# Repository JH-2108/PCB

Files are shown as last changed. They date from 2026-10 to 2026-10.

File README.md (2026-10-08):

# Small devboard 

A custom RP2040-based development board designed from scratch in KiCAD as part of Hack Club Half Life. 

The DevBoard is a compact general-purpose development platform with native USB-C connectivity, external QSPI flash, 3.3V power regulation, GPIO breakout, onboard controls, and a status LED. The board is intended to be used for embedded programming, electronics experimentation, robotics, sensors, displays, and future hardware projects. 

# Features 
- Raspberry Pi RP2040 microcontroller
- Native USB-C connectivity
- External QSPI flash
- 12 MHz crystal oscillator
- 3.3V power regulation
- 2x20 GPIO breakout pins
- BOOTSEL and RESET buttons
- Onboard status LED
- SMD components
- Custom PCB designed in KiCAD

# Hardware 
The board is built around the RP2040 and follows the required circuity for its power, clock, USB, and external flash interfaces. 

# Main components
- RP2040 MCU
- W25Q128 QSPI flash
- 12 MHz crystal
- USB-C connector
- 3.3V LDO regulator
- Decoupling and filtering capacitors
- USB-C CC resistors
- GPIO headers
- RESET and BOOTSEL buttons
- Status LED

# Firmware
The devboard will be programmed using the Raspberry Pi Pico SDK and C/C++. 

The initial firmware will provide: 
- RP2040 boot and initialization
- USB connectivity
- GPIO testing
- Status LED control
- Board diagnostics
- USB serial communication

A diagnostic firmware can be used to verify that the assembled PCB is functioning correctly. 

# PC software
A small optional Python utility may be developed to communicated with the board over USB serial. 

This can be used to 
- Display board information
- Run hardware tests
- Control the onboard LED
- Test GPIO
- Monitor diagnostic output

# Design
The PCB and schematic are designed using KiCAD. 
Project files include: 
- Schematic
- PCB layout
- Component/footprint assignments
- BOM
- Manufacturing files

# Design process
1. select and verify components for pricing and whether it is within budget range
2. create the schematic
3. assign symbols and footprints
4. design the PCB layout
5. route the board
6. run electrical and design rule checks
7. generate gerber files
8. assemble the PCB
9. develop and test firmware
10. test the complete board

# Project goals
The main goal is to design and build a fully functioning custom development board rather than relying on an existing development board such as the Raspberry Pi Pico. 

The project combines: 
- PCB design
- embedded systems
- electronics
- Firmware development
- USB communication
- hardware testing
- software development

# project images

**Schematic** 



**PCB layout**



**3d Render**



**Finished PCB**
a photo will be added here

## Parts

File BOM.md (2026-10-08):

# Simple devboard – bill of materials

<!-- Generated by Half Life from project cmuvnsb3i011801o9xqn8m9wa. Edits here are overwritten on the next sync. -->
<!-- Generated: 2026-10-07T17:44:08.035Z -->

> [!NOTE]
> This parts list is mirrored from [Half Life](https://halflife.hackclub.com). Editing it here will not change the platform's copy, and the next sync overwrites this file.

| Week | Tier | Parts funding |
| --- | --- | --- |
| Week 1 | Tier 1 | $30.00 |

| Part | What it's for | Qty | Unit | Total | Vendor |
| --- | --- | --- | --- | --- | --- |
| [Raspberry Pi RP2040CT](https://my.cytron.io/p-raspberry-pi-rp2040-mcu-ic-single-unit) | Main dual-core microcontroller unit | 1 | $1.15 | $1.15 | [Cytron](https://my.cytron.io/p-raspberry-pi-rp2040-mcu-ic-single-unit) |
| [Winbond W25Q128JVSIQ](https://www.lcsc.com/product-detail/C113767.html) | 128-Mbit QSPI flash for RP2040 firmware | 1 | $2.52 | $2.52 | [LCSC](https://www.lcsc.com/product-detail/C113767.html) |
| [12 MHz SMD crystal, 3225 4-pin](https://www.lcsc.com/product-detail/C518158.html) | RP2040 reference clock | 5 | $0.10 | $0.50 | [LCSC](https://www.lcsc.com/product-detail/C518158.html) |
| [USB Type-C 16-pin receptacle](https://shopee.com.my/Type-C-3.1-Patch-Socket-6P-16P-24P-Countersunk-Board-1.6-0.8mm-USB-Female-Socket-Data-Interface-i.513412485.42610897264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) | USB Data + 5V power | 1 | $0.65 | $0.65 | [Shopee Malaysia](https://shopee.com.my/Type-C-3.1-Patch-Socket-6P-16P-24P-Countersunk-Board-1.6-0.8mm-USB-Female-Socket-Data-Interface-i.513412485.42610897264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) |
| [3.3 V LDO regulator](https://shopee.com.my/AMS1117-Voltage-Regulator-IC-SOT-223-1.2V-1.5V-1.8V-2.5V-3.3V-5V-i.1412281456.49416215365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) | Converts USB 5V to 3.3V | 1 | $0.46 | $0.46 | [Shopee Malaysia](https://shopee.com.my/AMS1117-Voltage-Regulator-IC-SOT-223-1.2V-1.5V-1.8V-2.5V-3.3V-5V-i.1412281456.49416215365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) |
| [10 µF ceramic capacitor](https://shopee.com.my/50V-10uF-Multilayer-Capacitor-i.40459773.23082863550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) | Power filtering | 1 | $1.05 | $1.05 | [Shopee Malaysia](https://shopee.com.my/50V-10uF-Multilayer-Capacitor-i.40459773.23082863550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) |
| [100 nF ceramic capacitor](https://shopee.com.my/0402-0603-0805-1206-100nF-820nF-SMD-Chip-Capacitor-i.1467039591.41834021222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) | RP2040 / flash power decoupling | 1 | $1.25 | $1.25 | [Shopee Malaysia](https://shopee.com.my/0402-0603-0805-1206-100nF-820nF-SMD-Chip-Capacitor-i.1467039591.41834021222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) |
| [5.1 kΩ resistor](https://shopee.com.my/SMD-0402-0603-0805-1206-RESISTOR-1K-9.1K-Ohm-i.1467039591.50009312017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) | USB-C CC resistors | 1 | $1.24 | $1.24 | [Shopee Malaysia](https://shopee.com.my/SMD-0402-0603-0805-1206-RESISTOR-1K-9.1K-Ohm-i.1467039591.50009312017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) |
| [1 kΩ resistor](https://shopee.com.my/SMD-0402-0603-0805-1206-RESISTOR-1K-9.1K-Ohm-i.1467039591.50009312017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) | Limiting LED current flow | 1 | $1.24 | $1.24 | [Shopee Malaysia](https://shopee.com.my/SMD-0402-0603-0805-1206-RESISTOR-1K-9.1K-Ohm-i.1467039591.50009312017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) |
| [0603 LED](https://shopee.com.my/SMD-0402-0603-0805-1206-RESISTOR-1K-9.1K-Ohm-i.1467039591.50009312017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) | Status indicator | 1 | $0.88 | $0.88 | [Shopee Malaysia](https://shopee.com.my/SMD-0402-0603-0805-1206-RESISTOR-1K-9.1K-Ohm-i.1467039591.50009312017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) |
| [Tactile push button](https://shopee.com.my/Button-Switch-Tactile-Push-6x6x5mm-6*6*5mm-4PIN-i.482535902.11217352127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) | Resets RP2040 | 1 | $0.31 | $0.31 | [Shopee Malaysia](https://shopee.com.my/Button-Switch-Tactile-Push-6x6x5mm-6*6*5mm-4PIN-i.482535902.11217352127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) |
| [Tactile push button](https://shopee.com.my/Button-Switch-Tactile-Push-6x6x5mm-6*6*5mm-4PIN-i.482535902.11217352127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) | Enters RP2040 USB bootloader | 1 | $0.31 | $0.31 | [Shopee Malaysia](https://shopee.com.my/Button-Switch-Tactile-Push-6x6x5mm-6*6*5mm-4PIN-i.482535902.11217352127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) |
| [2.54 mm male pin headers](https://shopee.com.my/Male-Header-Pins-Straight-Single-Row-40-Pin-0.1-Inch-(2.54mm)-Male-Pin-Header-Connector-PCB-Board-Pin-Connect-i.161803224.7025057004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) | GPIO/power/peripheral breakout | 1 | $0.30 | $0.30 | [Shopee Malaysia](https://shopee.com.my/Male-Header-Pins-Straight-Single-Row-40-Pin-0.1-Inch-(2.54mm)-Male-Pin-Header-Connector-PCB-Board-Pin-Connect-i.161803224.7025057004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) |
| [Custom PCB](https://jlcpcb.com) | Main devboard / connectors | 1 | $5.78 | $5.78 | [JLCPCB](https://jlcpcb.com) |
| **Parts subtotal** | — | — | — | **$17.64** | — |
| **Tax & shipping** | — | — | — | **$12.25** | — |
| **Total** | — | — | — | **$29.89** | — |

$0.11 left of the tier's funding.

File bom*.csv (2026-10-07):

Reference | Qty | Value | DNP | Exclude from BOM | Exclude from Board | Exclude from Simulation | Exclude from Position Files | Footprint | Datasheet
C1,C2,C3,C4,C5,C6,C8 | 7 | 100nF |  |  |  |  | ${EXCLUDE_FROM_POS_FILES} | Capacitor_SMD:C_0603_1608Metric
C7 | 1 | 1uF |  |  |  |  | ${EXCLUDE_FROM_POS_FILES} | Capacitor_SMD:C_0603_1608Metric
C9 | 1 | 10uF |  |  |  |  | ${EXCLUDE_FROM_POS_FILES} | Capacitor_SMD:C_0603_1608Metric
D1 | 1 | LED |  |  |  |  | ${EXCLUDE_FROM_POS_FILES} | LED_SMD:LED_0603_1608Metric
J1 | 1 | USB_C_Receptacle_USB2.0_16P |  |  |  |  | ${EXCLUDE_FROM_POS_FILES} | Connector_USB:USB_C_Receptacle_GCT_USB4105-xx-A_16P_TopMnt_Horizontal | https://www.usb.org/sites/default/files/documents/usb_type-c.zip
J2,J3 | 2 | Conn_01x20 |  |  |  |  | ${EXCLUDE_FROM_POS_FILES} | Connector_PinHeader_2.54mm:PinHeader_1x20_P2.54mm_Vertical
R1,R2 | 2 | 5.1kΩ |  |  |  |  | ${EXCLUDE_FROM_POS_FILES} | Resistor_SMD:R_0603_1608Metric
R3 | 1 | 1kΩ |  |  |  |  | ${EXCLUDE_FROM_POS_FILES} | Resistor_SMD:R_0603_1608Metric
SW1 | 1 | RESET |  |  |  |  | ${EXCLUDE_FROM_POS_FILES} | Button_Switch_SMD:SW_Push_1P1T_NO_E-Switch_TL3301NxxxxxG
SW2 | 1 | BOOTSEL |  |  |  |  | ${EXCLUDE_FROM_POS_FILES} | Button_Switch_SMD:SW_Push_1P1T_NO_E-Switch_TL3301NxxxxxG
U1 | 1 | RP2040 |  |  |  |  | ${EXCLUDE_FROM_POS_FILES} | Package_DFN_QFN:QFN-56-1EP_7x7mm_P0.4mm_EP3.2x3.2mm | https://datasheets.raspberrypi.com/rp2040/rp2040-datasheet.pdf
U2 | 1 | W25Q128JVSIQ |  |  |  |  | ${EXCLUDE_FROM_POS_FILES} | Package_SO:SOIC-8_5.3x5.3mm_P1.27mm | https://www.winbond.com/resource-files/w25q128jv_dtr%20revc%2003272018%20plus.pdf
U3 | 1 | AP2112K-3.3 |  |  |  |  | ${EXCLUDE_FROM_POS_FILES} | Package_TO_SOT_SMD:SOT-23-5 | https://www.diodes.com/assets/Datasheets/AP2112.pdf
Y1 | 1 | 12MHz |  |  |  |  | ${EXCLUDE_FROM_POS_FILES} | Crystal:Crystal_SMD_3225-4Pin_3.2x2.5mm

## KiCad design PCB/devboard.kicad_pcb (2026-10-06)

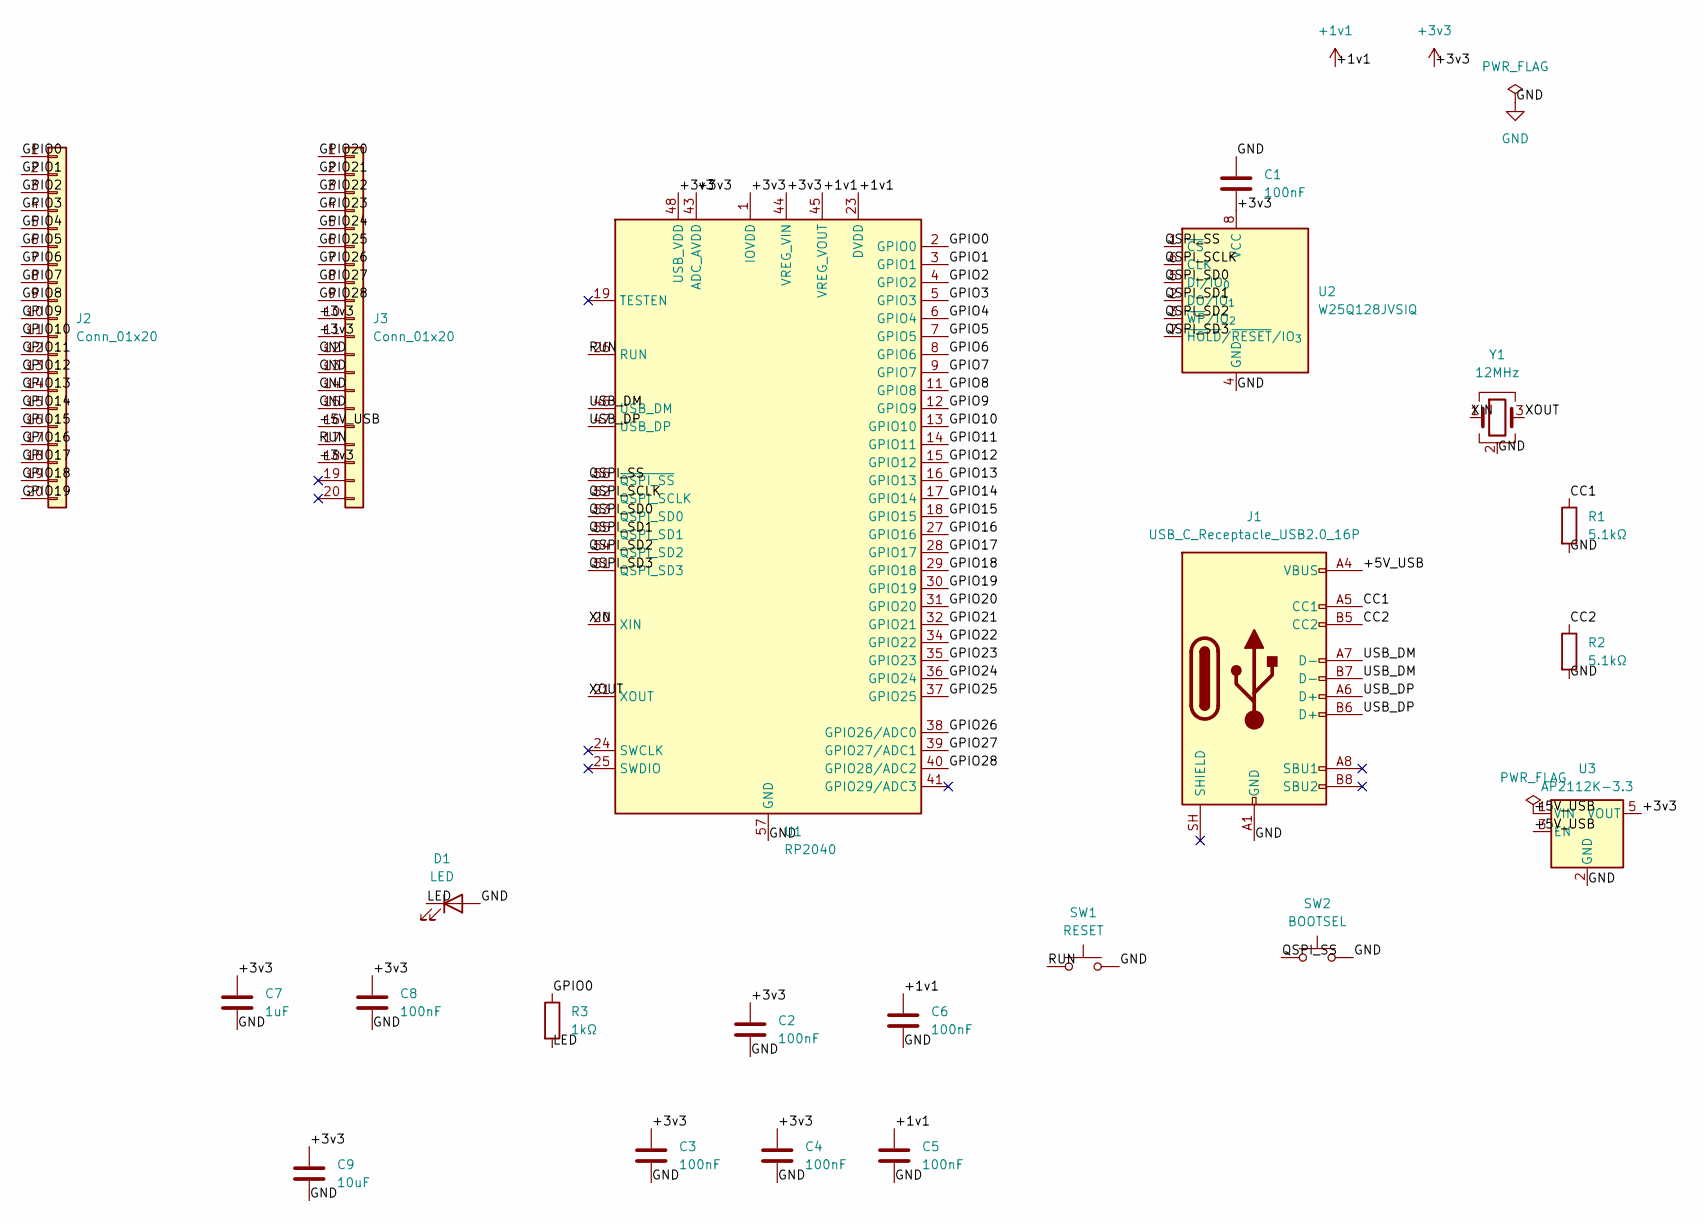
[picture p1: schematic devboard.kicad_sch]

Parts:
C1, C2, C3, C4, C5, C6, C8: 100nF; C_0603_1608Metric
C7: 1uF; C_0603_1608Metric
C9: 10uF; C_0603_1608Metric
D1: LED; LED_0603_1608Metric
J1: USB_C_Receptacle_USB2.0_16P; USB_C_Receptacle_GCT_USB4105-xx-A_16P_TopMnt_Horizontal
J2, J3: Conn_01x20; PinHeader_1x20_P2.54mm_Vertical
R1, R2: 5.1kΩ; R_0603_1608Metric
R3: 1kΩ; R_0603_1608Metric
SW1: RESET; SW_Push_1P1T_NO_E-Switch_TL3301NxxxxxG
SW2: BOOTSEL; SW_Push_1P1T_NO_E-Switch_TL3301NxxxxxG
U1: RP2040; QFN-56-1EP_7x7mm_P0.4mm_EP3.2x3.2mm
U2: W25Q128JVSIQ; SOIC-8_5.3x5.3mm_P1.27mm
U3: AP2112K-3.3; SOT-23-5
Y1: 12MHz; Crystal_SMD_3225-4Pin_3.2x2.5mm

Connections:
+1v1: C5.1, C6.1, U1.23 (DVDD), U1.45 (VREG_VOUT), U1.50 (DVDD)
+3v3: C1.2, C2.1, C3.1, C4.1, C7.1, C8.1, C9.1, J3.10, J3.11, J3.18, U1.1 (IOVDD), U1.10 (IOVDD), U1.22 (IOVDD), U1.33 (IOVDD), U1.42 (IOVDD), U1.43 (ADC_AVDD), U1.44 (VREG_VIN), U1.48 (USB_VDD), U1.49 (IOVDD), U2.8 (VCC), U3.5 (VOUT)
/+5V_USB: J1.A4 (VBUS), J1.A9 (VBUS), J1.B4 (VBUS), J1.B9 (VBUS), J3.16, U3.1 (VIN), U3.3 (EN)
/CC1: J1.A5 (CC1), R1.1
/CC2: J1.B5 (CC2), R2.1
/GPIO0: J2.1, R3.1, U1.2 (GPIO0)
/GPIO1: J2.2, U1.3 (GPIO1)
/GPIO2: J2.3, U1.4 (GPIO2)
/GPIO3: J2.4, U1.5 (GPIO3)
/GPIO4: J2.5, U1.6 (GPIO4)
/GPIO5: J2.6, U1.7 (GPIO5)
/GPIO6: J2.7, U1.8 (GPIO6)
/GPIO7: J2.8, U1.9 (GPIO7)
/GPIO8: J2.9, U1.11 (GPIO8)
/GPIO9: J2.10, U1.12 (GPIO9)
/GPIO10: J2.11, U1.13 (GPIO10)
/GPIO11: J2.12, U1.14 (GPIO11)
/GPIO12: J2.13, U1.15 (GPIO12)
/GPIO13: J2.14, U1.16 (GPIO13)
/GPIO14: J2.15, U1.17 (GPIO14)
/GPIO15: J2.16, U1.18 (GPIO15)
/GPIO16: J2.17, U1.27 (GPIO16)
/GPIO17: J2.18, U1.28 (GPIO17)
/GPIO18: J2.19, U1.29 (GPIO18)
/GPIO19: J2.20, U1.30 (GPIO19)
/GPIO20: J3.1, U1.31 (GPIO20)
/GPIO21: J3.2, U1.32 (GPIO21)
/GPIO22: J3.3, U1.34 (GPIO22)
/GPIO23: J3.4, U1.35 (GPIO23)
/GPIO24: J3.5, U1.36 (GPIO24)
/GPIO25: J3.6, U1.37 (GPIO25)
/GPIO26: J3.7, U1.38 (GPIO26/ADC0)
/GPIO27: J3.8, U1.39 (GPIO27/ADC1)
/GPIO28: J3.9, U1.40 (GPIO28/ADC2)
/LED: D1.1 (K), R3.2
/QSPI_SCLK: U1.52 (QSPI_SCLK), U2.6 (CLK)
/QSPI_SD0: U1.53 (QSPI_SD0), U2.5 (DI/IO_{0})
/QSPI_SD1: U1.55 (QSPI_SD1), U2.2 (DO/IO_{1})
/QSPI_SD2: U1.54 (QSPI_SD2), U2.3 (~WP/IO_{2})
/QSPI_SD3: U1.51 (QSPI_SD3), U2.7 (~HOLD/~RESET/IO_{3})
/QSPI_SS: SW2.1, U1.56 (~QSPI_SS), U2.1 (~CS)
/RUN: J3.17, SW1.1, U1.26 (RUN)
/USB_DM: J1.A7 (D-), J1.B7 (D-), U1.46 (USB_DM)
/USB_DP: J1.A6 (D+), J1.B6 (D+), U1.47 (USB_DP)
/XIN: U1.20 (XIN), Y1.1
/XOUT: U1.21 (XOUT), Y1.3
GND: C1.1, C2.2, C3.2, C4.2, C5.2, C6.2, C7.2, C8.2, C9.2, D1.2 (A), J1.A1 (GND), J1.A12 (GND), J1.B1 (GND), J1.B12 (GND), J3.12, J3.13, J3.14, J3.15, R1.2, R2.2, SW1.2, SW2.2, U1.57 (GND), U2.4 (GND), U3.2 (GND), Y1.2 (G), Y1.4 (G)

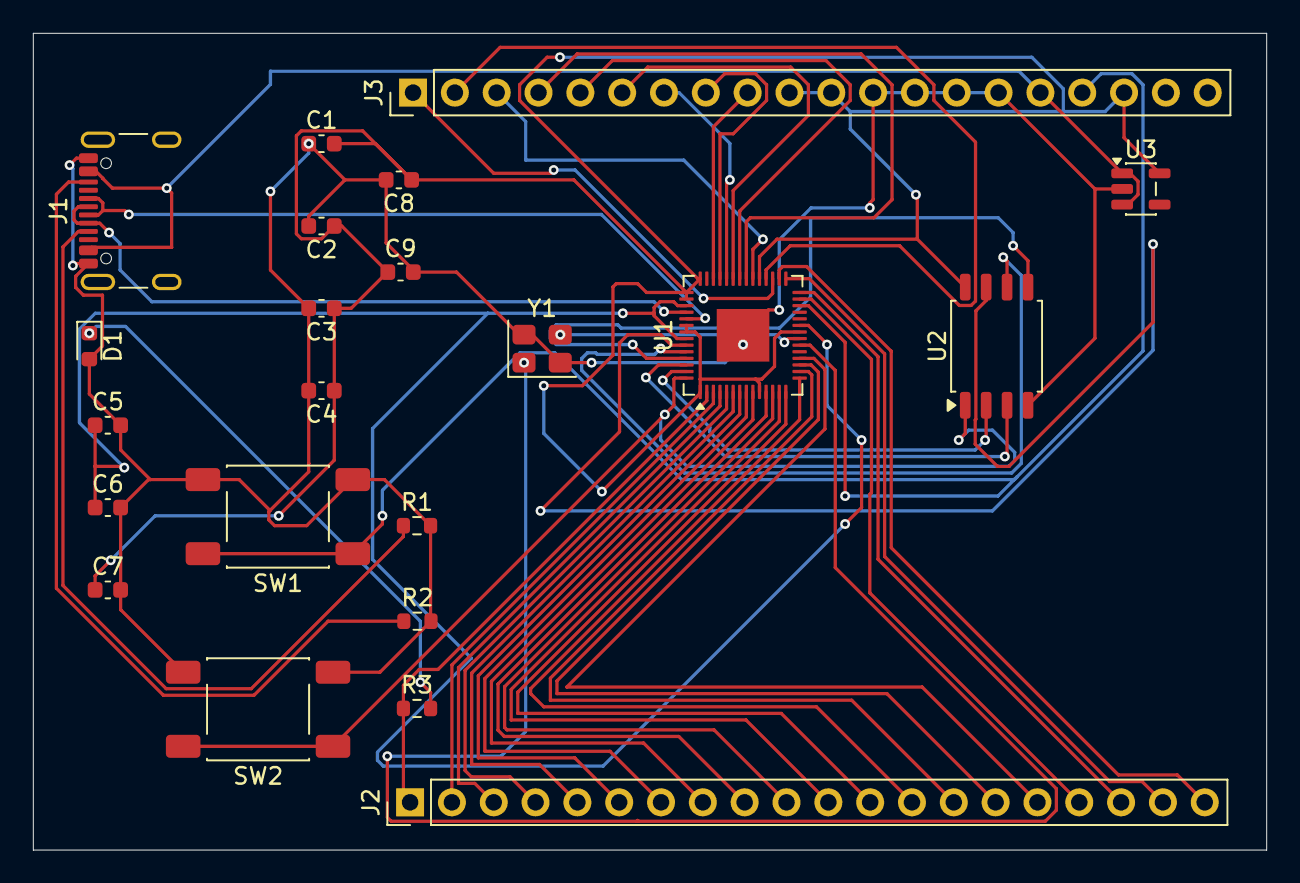
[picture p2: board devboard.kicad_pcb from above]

Board: 2 copper layers, 74.9 x 49.6 mm, 22 parts (0 on the bottom side), 47 nets.

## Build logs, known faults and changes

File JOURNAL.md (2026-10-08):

# Simple devboard – devlog

<!-- Generated by Half Life from project cmuvnsb3i011801o9xqn8m9wa. Edits here are overwritten on the next sync. -->
<!-- Generated: 2026-10-07T09:11:42.905Z -->

> [!NOTE]
> This devlog is mirrored from [Half Life](https://halflife.hackclub.com). Editing it here will not change the platform's copy, and the next sync overwrites this file.

> A custom-designed, compact development board built around the Raspberry Pi RP2040 microcontroller. The board includes native USB-C connectivity, external QSPI flash, 3.3V power regulation, BOOTSEL and reset controls, status indication, and 40GPO breakout pins. It is designed as a general purpose platform for experimenting with embedded programming, sensors, displays, robotics and future hardware projects.

| Week | Tier | Hours logged | Entries |
| --- | --- | --- | --- |
| Week 1 | Tier 1 | 11.1h | 3 |

## Contents

1. [2026-10-06 – **Finding an idea, learning KiCAD**](#2026-10-06-finding-an-idea-learning-kicad)
2. [2026-10-06 – **PCB DESIGNING**](#2026-10-06-pcb-designing)
3. [2026-10-07 – ](#2026-10-07-screenshot-2026-10-07-205429httpshalflifehackclub)

## Design

### 2026-10-06 – **Finding an idea, learning KiCAD**

**2h**

**Finding an idea, learning KiCAD**

Well, I had no idea what I wanted to do when I first started, maybe a flight controller (found out it was too expensive), a macropad (was a great idea, but I've done it before and I wanna do something different), a reaction game (tried that, deleted the project because it was a bit over the budget and way to easy), and then I landed on what I have now... A DEVBOARD!!!

Besides just making my idea reel, I also fully designed the entire PCB layout and schematics in KiCAD, successfully completing the creation of the entire DevBoard, which could be manufactured right now. However, you don't know me, I like to test if it works, and during my PCB layout creation, I faced so many difficulties, like the clearance issues on a FOOTPRINT, LITERALLY DESIGNED BY KICAD... Hence, I found a way to overcome it by changing the clearance value.

In the end, it took me 2 hours to work on the PCB layout, what type of parts to use, learning how to use KiCAD, while also checking if the parts that I need for this project are all on the KiCAD symbol and footprint library. It was a ton of work, but, hey, I finally did it, I got a great difficult project idea for a cost below 30usd, a PCB design that I can really work on, which will be quite fun to do so too, and how to solder those super tiny resistors and capacitors when the parts finally arrive at my doorstep!

To summarize what I did, I basically learnt how to use KiCAD, how to solder, and sketch up some ideas, and spent some of these time filming my reel!

Anyways, enough of my yapping, here are some images of my project:





### 2026-10-06 – **PCB DESIGNING**

**3.6h**

**PCB DESIGNING**

Some pictures of my PCB designing, includes the schematics, PCB, and 3d rendered version. An additional 1 hour and 30-ish minutes was used to handle certain PCB designing issues, and learning how KiCAD works! (including solving some problems that I had with KiCAD that isn't recorded in the timelapse.







[Timelapse](https://lookout.hackclub.com/api/media/49bfa0d1-a2d1-49ec-b1c6-9895ec110794/video.mp4)

[Timelapse](https://lookout.hackclub.com/api/media/312bf0b2-ec24-4d46-80e0-ec4d2dc14f10/video.mp4)

### 2026-10-07 – 

**5.5h**



**PREPARING FIRMWARE ENVIRONMENT**

Well, a development board doesn't always need a firmware for it to run, since, yk, the chips provide the main codes for all the other components to run along with how you are the one coding in order to make the devboard work.

However, as for me, I decided that, yk, I have a lot of free time, and also I haven't complete my 10 hour progress for this project, hence, I decided, why not I code the firmware to test the board first, then later on, when it is time to test the board, I'll just load the firmware onto the board and make sure it works. Hence, I took 4 hours of my time, downloading software, recoding certain firmwares and using a Raspberry Pi Pico extension from VSC to create an example project (blink), in hopes that when the parts for the devboard come, I am able to assemble it and build it.

You may be wondering, how did I spend 5 hours on downloading the softwares and all for the testing, well, there were a ton of compatibility issues, deleting my files over and over again, watched some tutorials on how to fix certain issues, and,  well, maybe use some ChatGPT to more efficiently solve them for me. But at least, at the end, I was able to solve all the issues that I was facing, successfully creating the testing environment for the devboard!

Below are the pictures of what I did, such as the download pages, the coding parts, and waiting a long time for some software to finish downloading!
